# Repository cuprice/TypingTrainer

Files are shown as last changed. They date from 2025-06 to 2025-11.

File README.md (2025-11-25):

## タイピング練習用キーボード基板 Typing Haptic Trainer (Prototype)

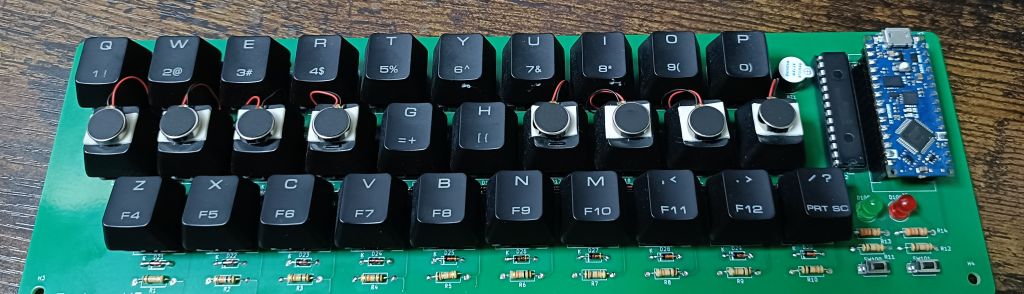
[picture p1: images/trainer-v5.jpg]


2025.11.25
Githubに公開してから数ヶ月経ちました。それ以来、触覚を利用したタッチタイピングの練習機械が他にもあることを知り、私のウェブ検索が十分でなかったと申し訳なく思いました。他の人々の作る機械はとても複雑でレベルの高いことも知り、私はまだまだ勉強不足であると思いました。もしお嫌でなければ、学習の活動を見守っていただければ幸いです。

I published my project on GitHub a few months ago.
After that, I learned that there are other typing training devices that use touch.
I felt sorry because my web search was not good enough.
I also found that other people’s devices are very complex and high-level, and I realized that I still have a lot to learn. If you don’t mind, I would be happy if you could watch my learning journey.

2025.11.23
基板を新しくしました！作った基板にArduino Nano Everyを組み込みました。
I made a new PCB and installed an Arduino Nano Every on it.

このリポジトリは回路・プログラミング初学者の学習用です。あたたかく見守っていただけると嬉しいです。

これは、プログラミングや回路の初心者である私が、自分なりに学びながら作ってみた実装基板です。  
8つのキーに振動する部品を付け、目で確認しなくてもどこを押せば良いかがわかる機能を目指しました。
公開しようと思ったきっかけは、似たようなアイデアのタイピング練習機を見つけることができなかったためです。

このリポジトリでは、タイピング練習を目的としたキーボード基板の設計データを公開しています。  
基板はKiCad 9.0で設計されています。振動するキー順番を変更するには、Arduinoのスケッチを編集する必要があります。

ただし、現在はアイデア段階であり、完全な完成品ではありません。今後の改善や追加機能に関しては更新を行う予定です。

This repository is for beginners who are learning circuits and programming.
I’d be happy if you could kindly support it.

This is a keyboard I made while learning programming and circuits by myself.
I am still a beginner, but I tried my best to build it.

I added small parts that can vibrate to 8 keys.
This way, you can feel which key to press without looking.

I decided to share this because I couldn't find a similar typing practice device online.

In this repository, I show the design data for this keyboard.
I made the design using KiCad 9.0.
If you want to change the order of the vibrating keys, you need to change the Arduino program.

Please note that this is still just an idea, not a finished product.
I want to improve it and add more features in the future.

---

## 特徴

- 10列、3段のキー(計30個)による練習用構成
- リセットスイッチ付き
- Cherry MX対応
- Arduino nano everyで完璧ではありませんが、一応動作確認済みです (後継機のモデルは動作未確認)
- KiCad 9.0で基板設計
- 基板サイズ：約261.1mm × 81.5mm
- 電源：Arduino nano every経由でのUSB給電

This is a practice keyboard layout with 30 keys, arranged in 10 columns and 3 rows.
It includes a reset switch. It's compatible with Cherry MX switches. I've confirmed it works with the Arduino nano every, although it's not perfect. I haven't tested it with newer Arduino models. The circuit board was designed using KiCad 9.0. The board size is about 261.1mm × 81.5mm, and it's powered by USB through the Arduino nano every.

どの段のキーを押せば良いかを、3段階のブザー音で教えるためのコードを加筆修正しました。上の段ならば3回鳴り、下の段ならば１回鳴り、真ん中の段なら２回鳴るという仕組みにしました。振動モーターがないキーの場合は、振動する長さを変えて位置を知らせるようにしました。

I changed the code to use three kinds of buzzer sounds to tell the user which row of keys to press.
If the key is on the top row, the buzzer beeps three times.
If the key is on the bottom row, it beeps one time.
If the key is on the middle row, it beeps two times.
For keys that do not have a vibration motor, the device changes the length of the vibration to show the position.

---

## ファイル構成

~~~

TypingTrainer/
    ├── TYPING-TRAINER-V5-2025-10-13_115341/ # KiCad設計ファイル
    ├── TYPING-TRAINER-V5.1.zip # ガーバーデータ（基板製造用）
    ├── TrainerV5active/ # Arduinoスケッチ
    ├── images/ # 写真・完成図
    ├── docs/ # 部品表
    └── README.md # このファイル

~~~

---

## 完成イメージ、回路図、動作の様子

基板写真

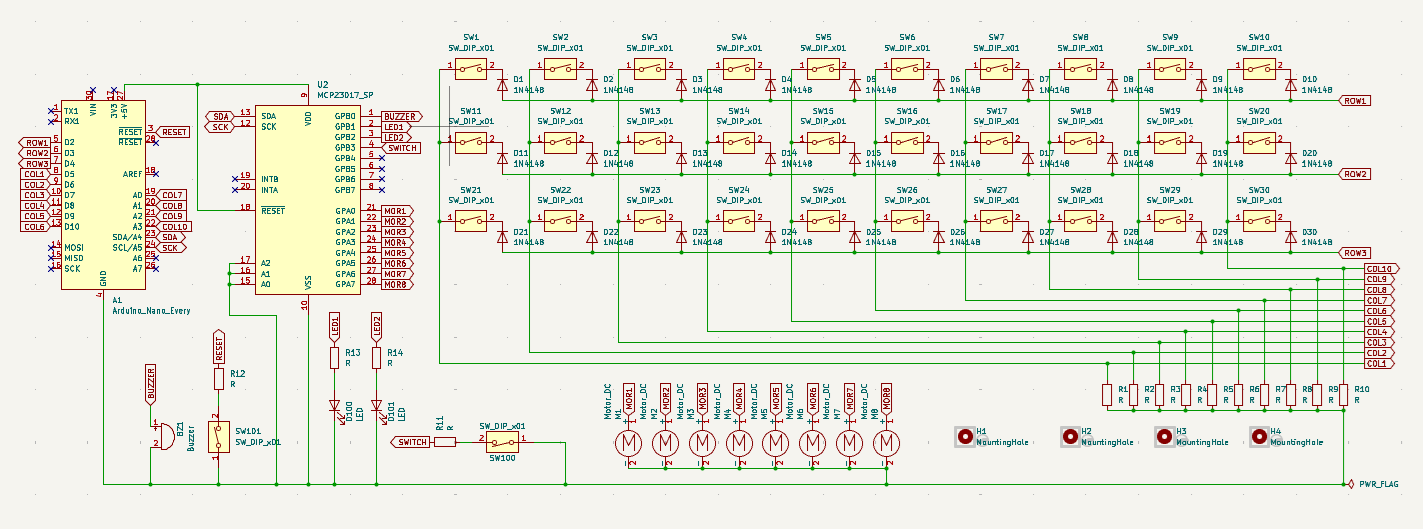
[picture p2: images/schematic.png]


[動作の様子](images/working.mp4)

[モーターの動き](images/shaker.mp4)

---

## 使い方
1. ガーバーファイルをPCBwayなどで製造依頼
2. 回路図などを見ながら部品を実装
3. Arduino nano everyをUSBケーブルでPCと接続
4. PCからArduinoへ、ファームウェアを書き込み

---

## 必要部品

| Value | Reference | Qty | 備考 | 画像 |
|---|---|-----|---|---|
| Arduino Nano Every  | A1 | 1 | マイクロコントローラー（ソケットピン経由で実装） |  |
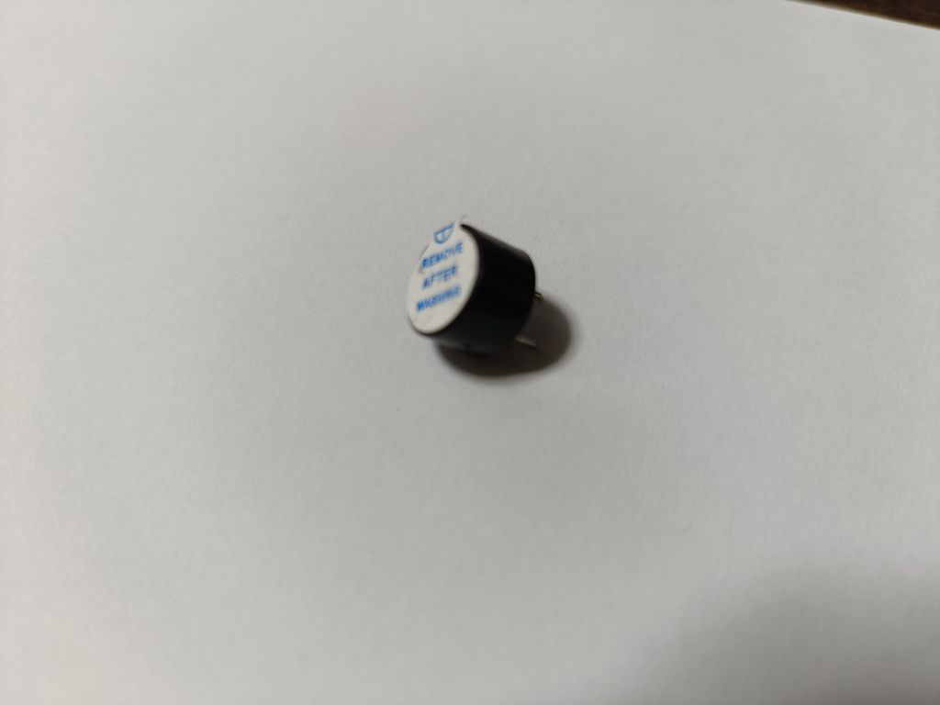
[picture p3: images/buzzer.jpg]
| Buzzer | BZ1 | 1 | ブザー |  |
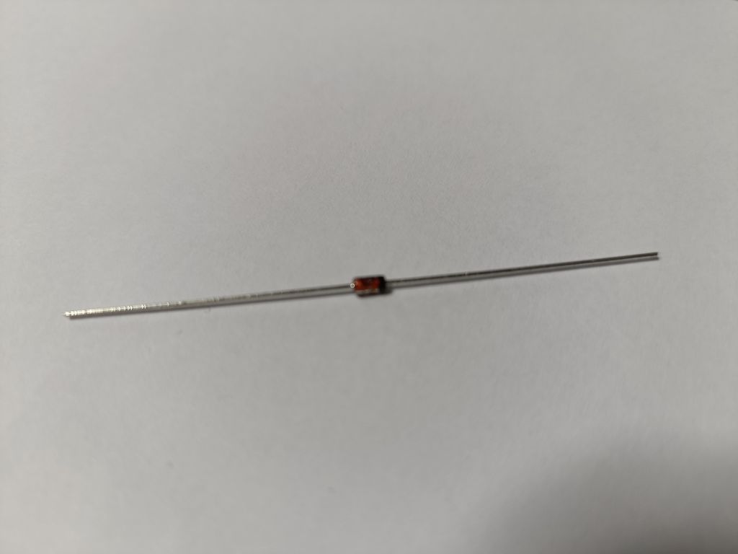
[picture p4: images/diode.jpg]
| 1N4148 | D1 〜 D30 | 30  | スイッチのマトリックス用ダイオード |  |
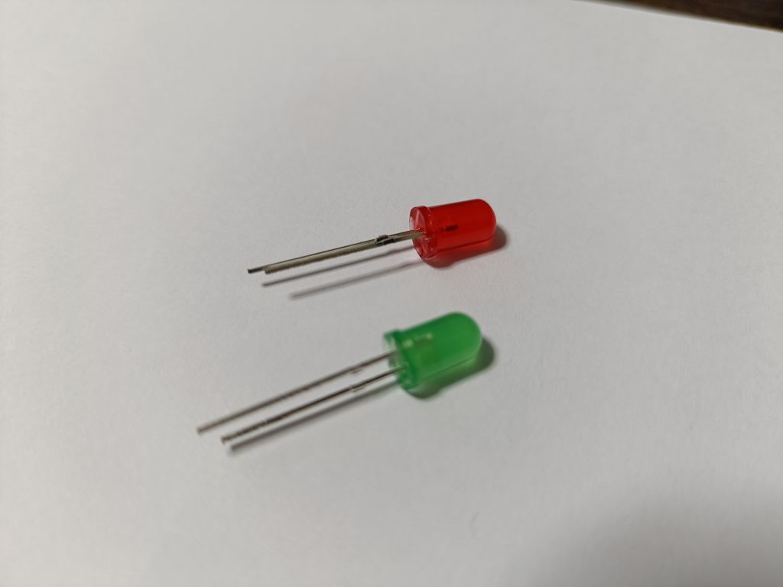
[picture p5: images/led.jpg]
| LED | D100, D101 | 2 | インジケーターLED |  |
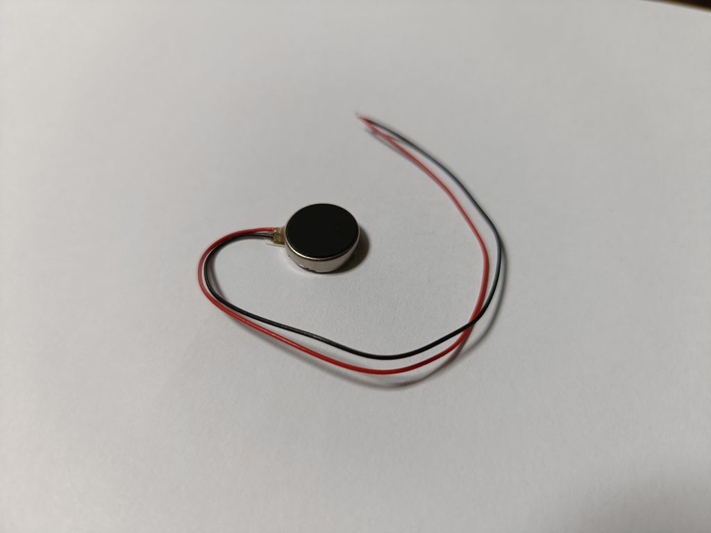
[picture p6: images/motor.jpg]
| Motor DC | M1 〜 M8 | 8 | DCモーター |  |
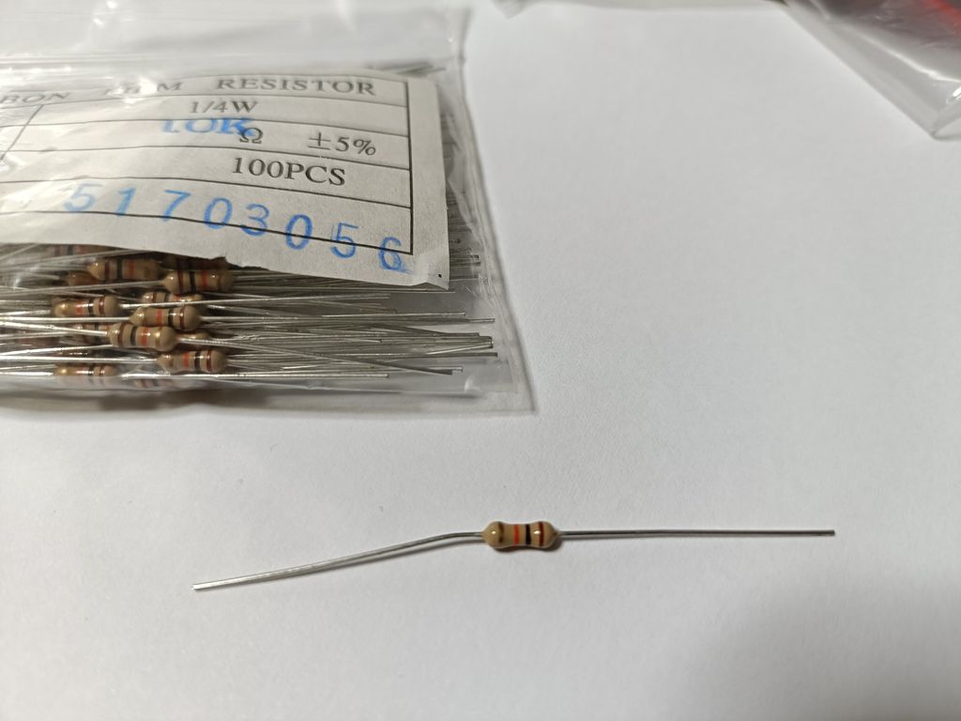
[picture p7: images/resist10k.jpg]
| 10k | R1 〜 R12 | 12  | 抵抗（10kΩ） |  |
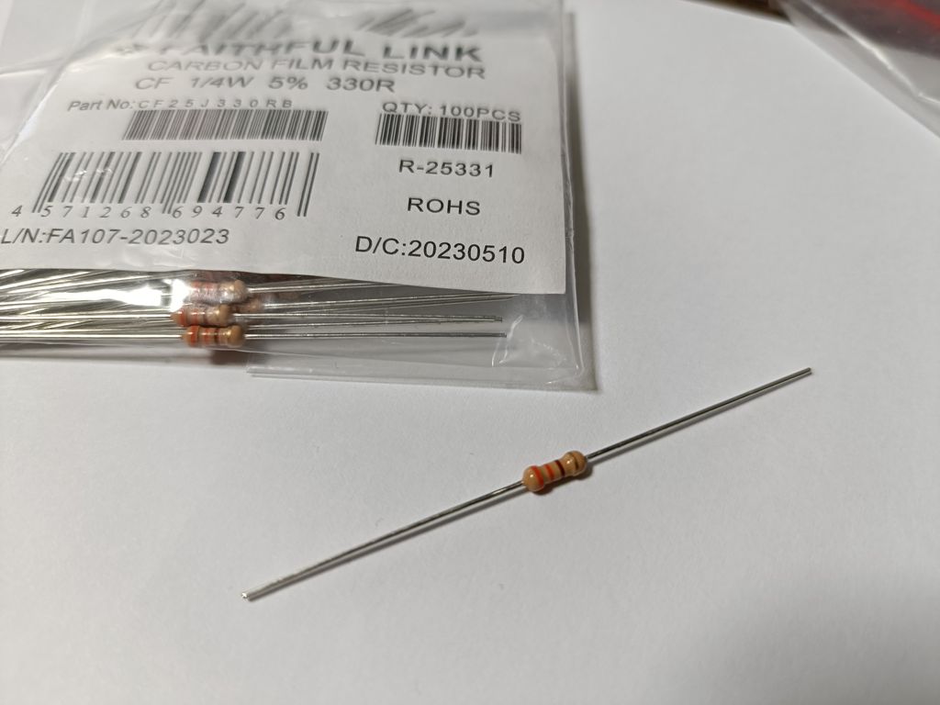
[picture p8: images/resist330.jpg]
| 330 | R13, R14 | 2 | 抵抗（330Ω, LED電流制限用） |  |
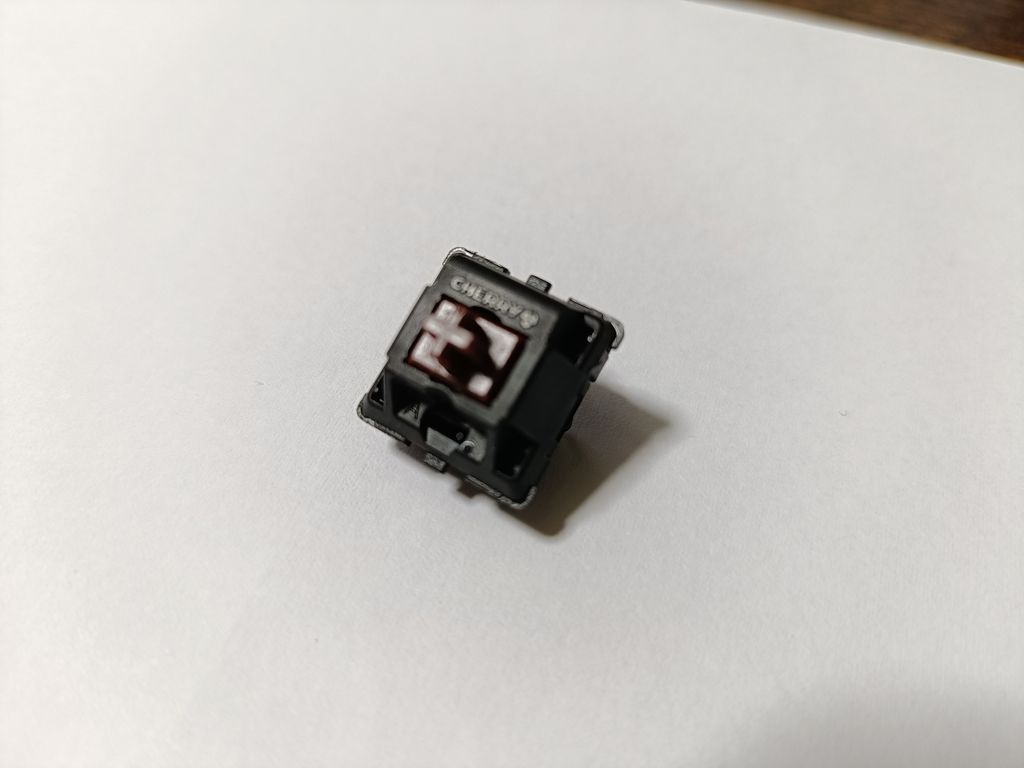
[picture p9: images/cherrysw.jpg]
| Cherry MX Switch | SW1 〜 SW30 | 30  | Cherry MX互換キースイッチ(キーキャップはお好みで) |  |
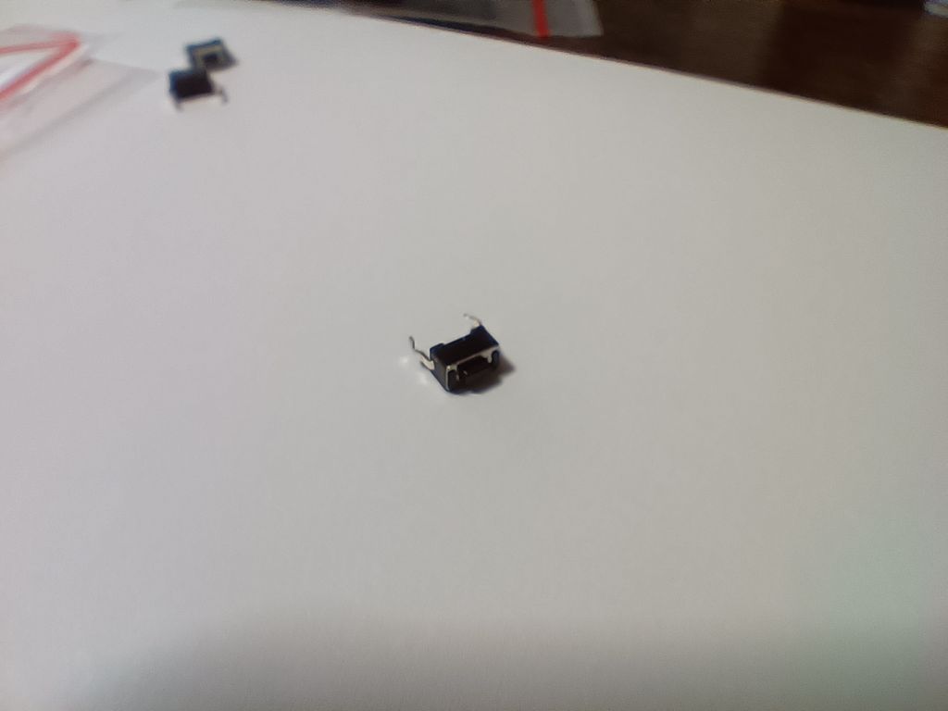
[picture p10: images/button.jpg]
| 2pin Button | SW100, SW101 | 2 | 2ピンのタクトスイッチなど |  |
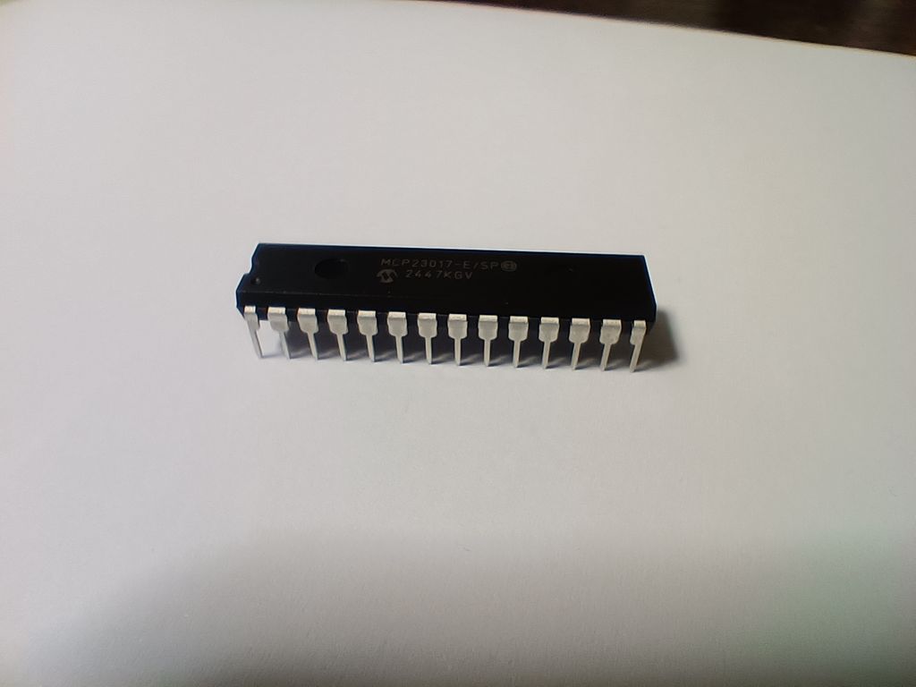
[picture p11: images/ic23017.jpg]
| MCP23017_SP | U2 | 1 | I/Oエキスパンダー（ICソケットの上に実装） |  |

---

## KiCad情報

- KiCad バージョン: 9.0
- 古いバージョンでは一部ファイルが開けない可能性があります。
- 最新バージョンでの動作は未確認です。

---

## ライセンス

この基板デザインは MIT ライセンスで公開しています。  

---

## よくある質問

準備中
**Q. ？**  
A. 

---

## 注意事項

- 初心者が学びながら作ったものなので、不完全な点もあるかもしれません。
- Arduinoスケッチの一部のコード作成に、生成AI（ChatGPT）を補助的に活用しました。

---

## Special Thanks

- ネット上のチュートリアルや電子工作記事の皆さま

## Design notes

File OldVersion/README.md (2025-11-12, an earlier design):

2025.11.12 今後の予定 Future Plan
基板にArduino Nano Everyを乗せる。AからZまでのキーを押せるようにする

I’m going to put an Arduino Nano Every on the board and make it work with keys from A to Z.

基板写真

2025.8.2 更新
どの段のキーを押せば良いかを、3段階のブザー音で教えるためのコードを加筆修正しました。上の段ならば高めの音、下の段ならば低めの音、真ん中の段ならその中間の音という仕組みにしました。

I changed the code to help users know which row of keys to press by using three different buzzer sounds.
A high sound means the top row, a low sound means the bottom row, and a middle sound means the middle row.

2025.7.27 追記
Arduinoのスケッチを、AIを使用して加筆修正し、複数の段にまたがって順番を指定できるように変更しました。また、段を切り替えるボタンは無効となっています。フォルダ名は、TrainerV4-i

I edited the Arduino sketch using AI. Now, you can set the order across several steps. The button to change steps is disabled. The folder name is TrainerV4-i.

## タイピング練習用キーボード基板
このリポジトリは回路・プログラミング初学者の学習用です。あたたかく見守っていただけると嬉しいです。

これは、プログラミングや回路の初心者である私が、自分なりに学びながら作ってみた実装基板です。  
8つのキーに振動する部品を付け、目で確認しなくてもどこを押せば良いかがわかる機能を目指しました。
公開しようと思ったきっかけは、似たようなアイデアのタイピング練習機を見つけることができなかったためです。

このリポジトリでは、タイピング練習を目的としたキーボード基板の設計データを公開しています。  
基板はKiCad 8.0で設計されています、基板上に部品を実装し、Arduino Uno R3に接続すれば使えるようになっています。
振動するキー順番を変更するには、Arduinoのスケッチを編集する必要があります。

ただし、現在はアイデア段階であり、完全な完成品ではありません。今後の改善や追加機能に関しては更新を行う予定です。

This repository is for beginners who are learning circuits and programming.
I’d be happy if you could kindly support it.

This is a keyboard I made while learning programming and circuits by myself.
I am still a beginner, but I tried my best to build it.

I added small parts that can vibrate to 8 keys.
This way, you can feel which key to press without looking.

I decided to share this because I couldn't find a similar typing practice device online.

In this repository, I show the design data for this keyboard.
I made the design using KiCad 8.0.
If you put the parts on the board and connect it to an Arduino Uno R3, it will work.
If you want to change the order of the vibrating keys, you need to change the Arduino program.

Please note that this is still just an idea, not a finished product.
I want to improve it and add more features in the future.

---

## 特徴

- 8列、3段のキー(計24個)による練習用構成
- リセットスイッチ、段の変更スイッチ機能付き
- Cherry MX対応
- Arduino Uno R3で完璧ではありませんが、一応動作確認済みです (後継機のモデルは動作未確認)
- KiCad 8.0で基板設計
- 基板サイズ：約215.9mm × 104.1mm
- 電源：Arduino Uno R3経由でのUSB給電

This is a practice keyboard layout with 24 keys, arranged in 8 columns and 3 rows.
It includes a reset switch and a switch to change the rows. It's compatible with Cherry MX switches. I've confirmed it works with the Arduino Uno R3, although it's not perfect. I haven't tested it with newer Arduino models. The circuit board was designed using KiCad 8.0. The board size is about 215.9mm x 104.1mm, and it's powered by USB through the Arduino Uno R3.

---

## ファイル構成

~~~

TypingTrainer/
    ├── TYPING-TRAINER-V4/ # KiCad設計ファイル
    ├── TYPING-TRAINER-V4.zip # ガーバーデータ（基板製造用）
    ├── TrainerV4_h-custom/ # Arduinoスケッチ
    ├── TrainerV4-i/ # Arduinoスケッチ (複数の段用スケッチ)
    ├── TrainerV4_i_example_words/ # Arduinoスケッチ (例文を使ったスケッチ)
    ├── images/ # 写真・完成図
    ├── docs/ # 部品表、ピン配置
    └── README.md # このファイル

~~~

---

## 完成イメージ

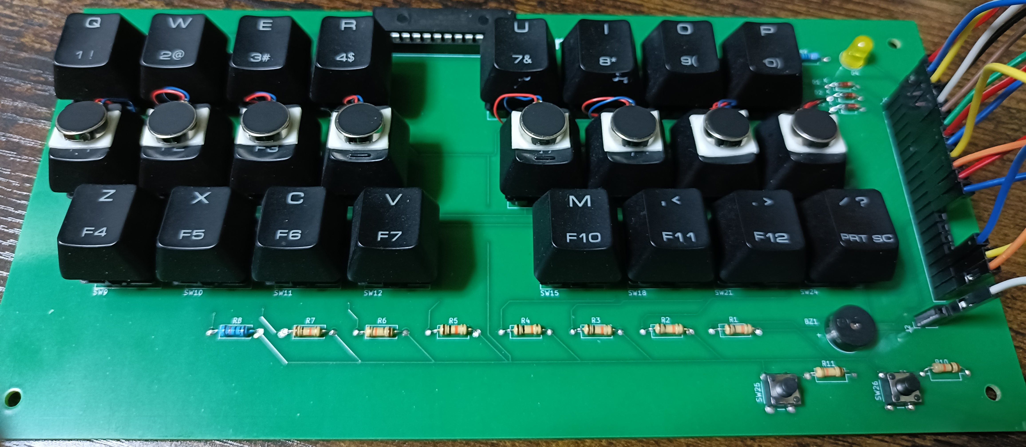
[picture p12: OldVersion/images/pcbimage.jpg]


---

## 使い方
1. ガーバーファイルをPCBwayなどで製造依頼
2. 回路図などを見ながら部品を実装
3. Arduino Uno R3と基板をジャンパワイヤで接続後、ArduinoをUSBケーブルでPCと接続
4. PCからArduinoへ、ファームウェアを書き込み

---

## 必要部品

| パーツ | 型番 / 種類 | 数量 | 備考 |
| :--- | :--- | :--- | :--- |
| マイコン | Arduino Uno R3 | 1個  | |
| USBケーブル | USB-A to USB-B | 1本  | PC接続用 |
| I/Oエキスパンダー | MCP23017 | 1個  | |
| ICソケット | 28ピン スリム300milタイプ | 1個  | IC直付けなら不要 |
| メカニカルスイッチ | Cherry MX互換  5ピン | 24個 | |
| キーキャップ | 上記スイッチ対応のもの | 24個 | |
| ダイオード | 1N4148 | 3個  | キーマトリクス用 |
| 抵抗 | 10kオーム | 10個 | |
| 抵抗 | 330オーム | 1個  | |
| LED (5mm) | 色はお好みで | 1個  | |
| タクトスイッチ | | 2個  | |
| パッシブ電子ブザー | | 1個  | \*1 |
| 振動モーター | | 8個  | |
| コネクタ用のピンソケット | 20pin | 1個  | |
| コネクタ用のピンソケット | 2pin | 1個  | |
| ジャンパ線 | 10cm～20cm | 20本くらいあれば | 

*1 ブザーのフットプリント参考URL https://jp.sameskydevices.com/product/resource/pcbfootprint/cmt-9648-85t

---

## KiCad情報

- KiCad バージョン: 8.0
- 古いバージョンでは一部ファイルが開けない可能性があります。
- 最新バージョンでの動作は未確認です。

---

## ライセンス

この基板デザインは MIT ライセンスで公開しています。  

---

## よくある質問

準備中
**Q. ？**  
A. 

---

## 注意事項

- 初心者が学びながら作ったものなので、不完全な点もあるかもしれません。
- Arduinoスケッチの一部のコード作成に、生成AI（ChatGPT）を補助的に活用しました。

---

## Special Thanks

- ネット上のチュートリアルや電子工作記事の皆さま

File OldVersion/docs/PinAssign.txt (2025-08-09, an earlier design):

20pin connector			
(TypingTrainer)          (Arduino)	
1pin  -----------------> 2pin	digital
2pin  -----------------> 3pin	digital
3pin  -----------------> 4pin	digital
4pin  -----------------> 5pin	digital
5pin  -----------------> 6pin	digital
6pin  -----------------> 7pin	digital
7pin  -----------------> 8pin	digital
8pin  -----------------> 9pin	digital
9pin  -----------------> 10pin	digital
10pin -----------------> 11pin	digital
11pin -----------------> 12pin	digital
12pin -----------------> A0	analog
13pin -----------------> 13pin	digital
14pin -----------------> n/a	
15pin -----------------> n/a	
16pin -----------------> A2	analog
17pin -----------------> A1	analog
18pin -----------------> A5	analog
19pin -----------------> A4	analog
20pin -----------------> 5V	
			
2pin connector --------> GND

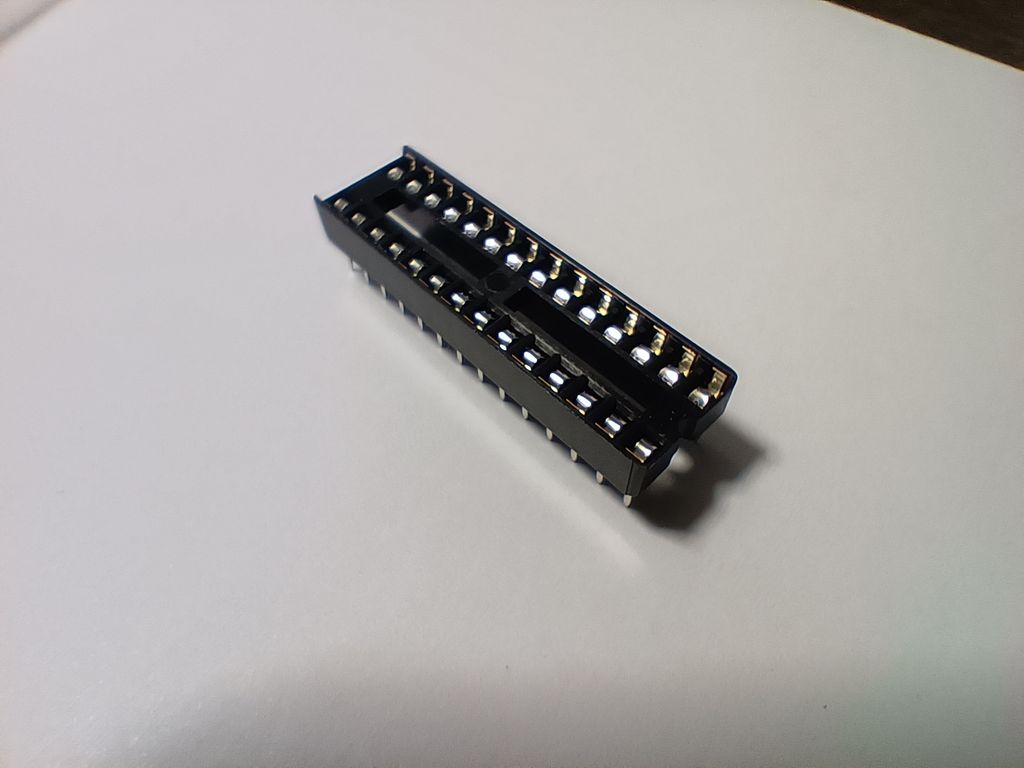
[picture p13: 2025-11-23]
images/icsocket.jpg

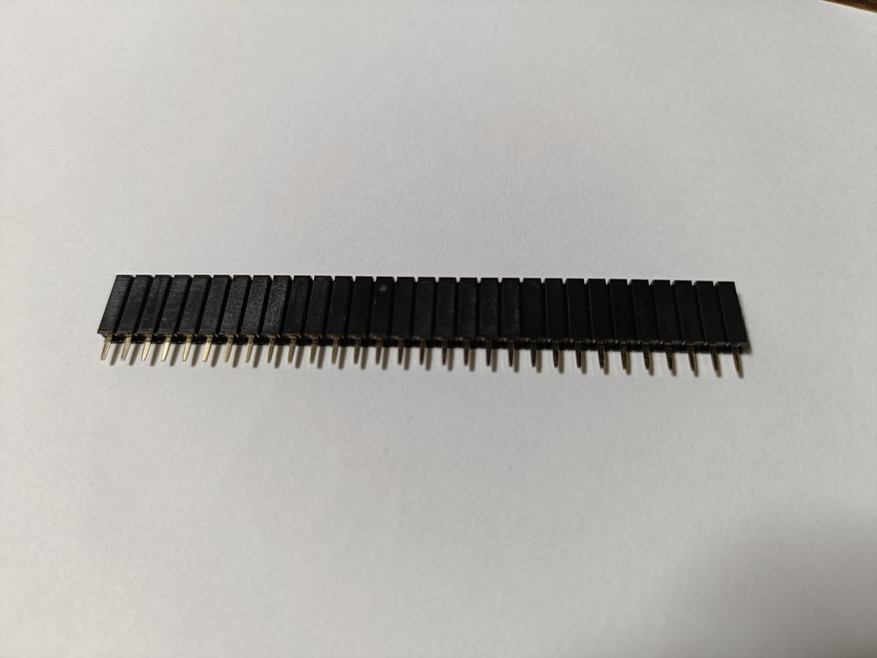
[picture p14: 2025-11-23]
images/socketpin.jpg

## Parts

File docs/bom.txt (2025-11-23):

Value	                Reference	Qty	備考
Arduino Nano Every	A1	        1	マイクロコントローラー
Buzzer	                BZ1	        1	ブザー
1N4148	                D1 〜 D30	30	スイッチのマトリックス用ダイオード
LED	                D100, D101	2	インジケーターLED
Motor DC              	M1 〜 M8	        8	DCモーター
10k	                R1 〜 R12	12	抵抗 (10kΩ)
330	                R13, R14	2	抵抗 (330Ω, LED電流制限用)
cherry mx switch	SW1 〜 SW30	30	Cherry MX互換キースイッチ
2pin button	        SW100, SW101	2	2ピンのタクトスイッチなど
MCP23017_SP	        U2	        1	I/Oエキスパンダー

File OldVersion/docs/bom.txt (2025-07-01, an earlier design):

# PartsList

| Value | Reference | Qty | DNP |
| :--- | :--- | :-- | :-- |
| Buzzer | BZ1 | 1 | |
| 1N4148 | D1,D2,D3 | 3 | |
| LED 5mm | D4 | 1 | |
| 20pin PInSocket | J1 | 1 | |
| 2pin PinSocket | J2 | 1 | |
| Motor_DC | M1,M2,M3,M4,M5,M6,M7,M8 | 8 | |
| 10k | R1,R2,R3,R4,R5,R6,R7,R8,R10,R11 | 10  | |
| 330 | R9 | 1 | |
| CherryMX Switch | SW1,SW2,SW3,SW4,SW5,SW6,SW7,SW8,SW9,SW10,SW11,SW12, | | |
| | SW13,SW14,SW15,SW16,SW17,SW18,SW19,SW20,SW21,SW22,SW23,SW24 | 24  | |
| Button Switch | SW25,SW26 | 2 | |
| MCP23017 | U2 | 1 | |

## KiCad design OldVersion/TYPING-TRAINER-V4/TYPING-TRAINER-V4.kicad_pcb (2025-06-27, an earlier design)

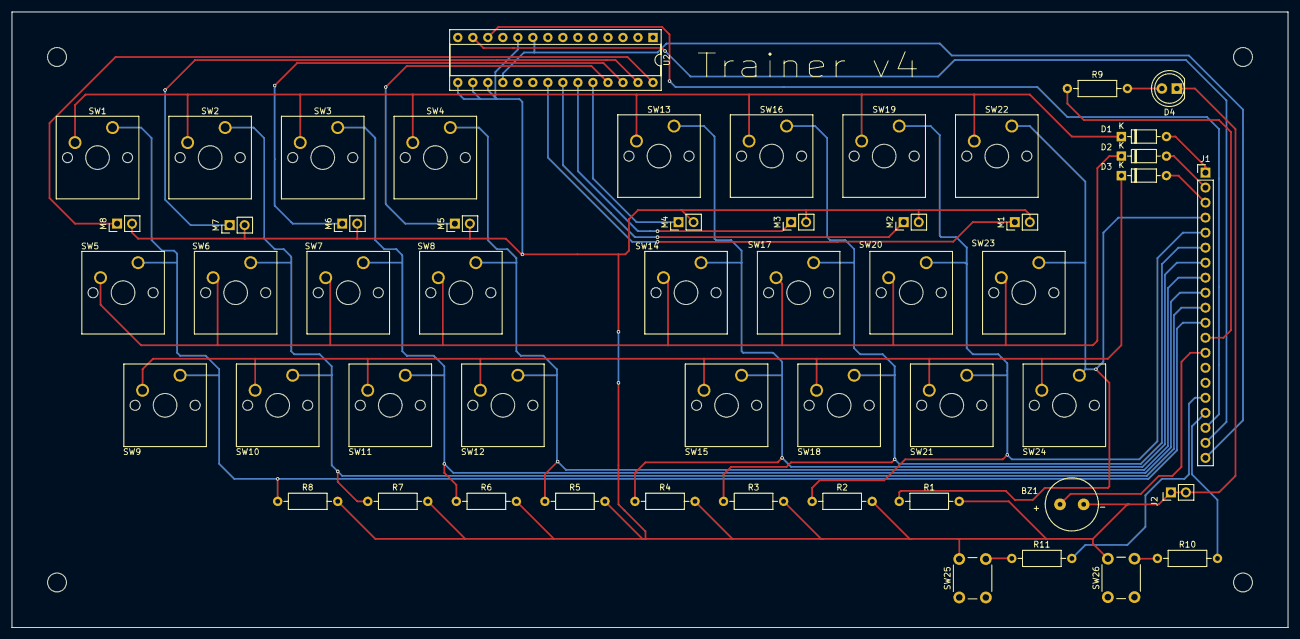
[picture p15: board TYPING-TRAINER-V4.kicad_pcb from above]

Board: 2 copper layers, 215.9 x 104.1 mm, 57 parts (0 on the bottom side), 33 nets.

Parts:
BZ1: Buzzer; XDCR_CMT-9648-85T
D1, D2, D3: 1N4148; D_DO-35_SOD27_P7.62mm_Horizontal
D4: LED; LED_D5.0mm_FlatTop
H1, H2, H3, H4: MountingHole; MountingHole_3.2mm_M3
J1: Conn_01x20_Pin; PinHeader_1x20_P2.54mm_Vertical
J2: Conn_01x02_Pin; PinHeader_1x02_P2.54mm_Vertical
M1, M2, M3, M4, M5, M6, M7, M8: Motor_DC; PinHeader_1x02_P2.54mm_Vertical
R1, R2, R3, R4, R5, R6, R7, R8, R9, R10, R11: R; R_Axial_DIN0207_L6.3mm_D2.5mm_P10.16mm_Horizontal
SW1, SW2, SW3, SW4, SW5, SW6, SW7, SW8, SW9, SW10, SW11, SW12, SW13, SW14, SW15, SW16, SW17, SW18, SW19, SW20, SW21, SW22, SW23, SW24: SW_DIP_x01; SW_Cherry_MX_1.00u_PCB
SW25, SW26: SW_DIP_x02b; SW_PUSH_6mm
U2: MCP23017_SP; CERDIP-28_W7.62mm_SideBrazed_Socket

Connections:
+5V: J1.20, U2.9 (VDD), U2.18 (~RESET)
GND: BZ1.2 (-), D4.1 (K), J2.1, J2.2, M1.2 (-), M2.2 (-), M3.2 (-), M4.2 (-), M5.2 (-), M6.2 (-), M7.2 (-), M8.2 (-), R1.2, R2.2, R3.2, R4.2, R5.2, R6.2, R7.2, R8.2, SW25.1, SW26.1, U2.10 (VSS), U2.15 (A0), U2.16 (A1), U2.17 (A2)
unnamed: BZ1.1 (+), J1.13
unnamed: D1.2 (A), J1.1
unnamed: D1.1 (K), SW1.2, SW2.2, SW3.2, SW4.2, SW13.2, SW16.2, SW19.2, SW22.2
unnamed: D2.2 (A), J1.2
unnamed: D2.1 (K), SW5.2, SW6.2, SW7.2, SW8.2, SW14.2, SW17.2, SW20.2, SW23.2
unnamed: D3.2 (A), J1.3
unnamed: D3.1 (K), SW9.2, SW10.2, SW11.2, SW12.2, SW15.2, SW18.2, SW21.2, SW24.2
unnamed: D4.2 (A), R9.2
unnamed: J1.4, R1.1, SW22.1, SW23.1, SW24.1
unnamed: J1.5, R2.1, SW19.1, SW20.1, SW21.1
unnamed: J1.6, R3.1, SW16.1, SW17.1, SW18.1
unnamed: J1.7, R4.1, SW13.1, SW14.1, SW15.1
unnamed: J1.8, R5.1, SW4.1, SW8.1, SW12.1
unnamed: J1.9, R6.1, SW3.1, SW7.1, SW11.1
unnamed: J1.10, R7.1, SW2.1, SW6.1, SW10.1
unnamed: J1.11, R8.1, SW1.1, SW5.1, SW9.1
unnamed: J1.12, R9.1
unnamed: J1.16, R11.2
unnamed: J1.17, R10.2
unnamed: J1.18, U2.12 (SCK)
unnamed: J1.19, U2.13 (SDA)
unnamed: M1.1 (+), U2.21 (GPA0)
unnamed: M2.1 (+), U2.22 (GPA1)
unnamed: M3.1 (+), U2.23 (GPA2)
unnamed: M4.1 (+), U2.24 (GPA3)
unnamed: M5.1 (+), U2.25 (GPA4)
unnamed: M6.1 (+), U2.26 (GPA5)
unnamed: M7.1 (+), U2.27 (GPA6)
unnamed: M8.1 (+), U2.28 (GPA7)
unnamed: R10.1, SW26.2
unnamed: R11.1, SW25.2

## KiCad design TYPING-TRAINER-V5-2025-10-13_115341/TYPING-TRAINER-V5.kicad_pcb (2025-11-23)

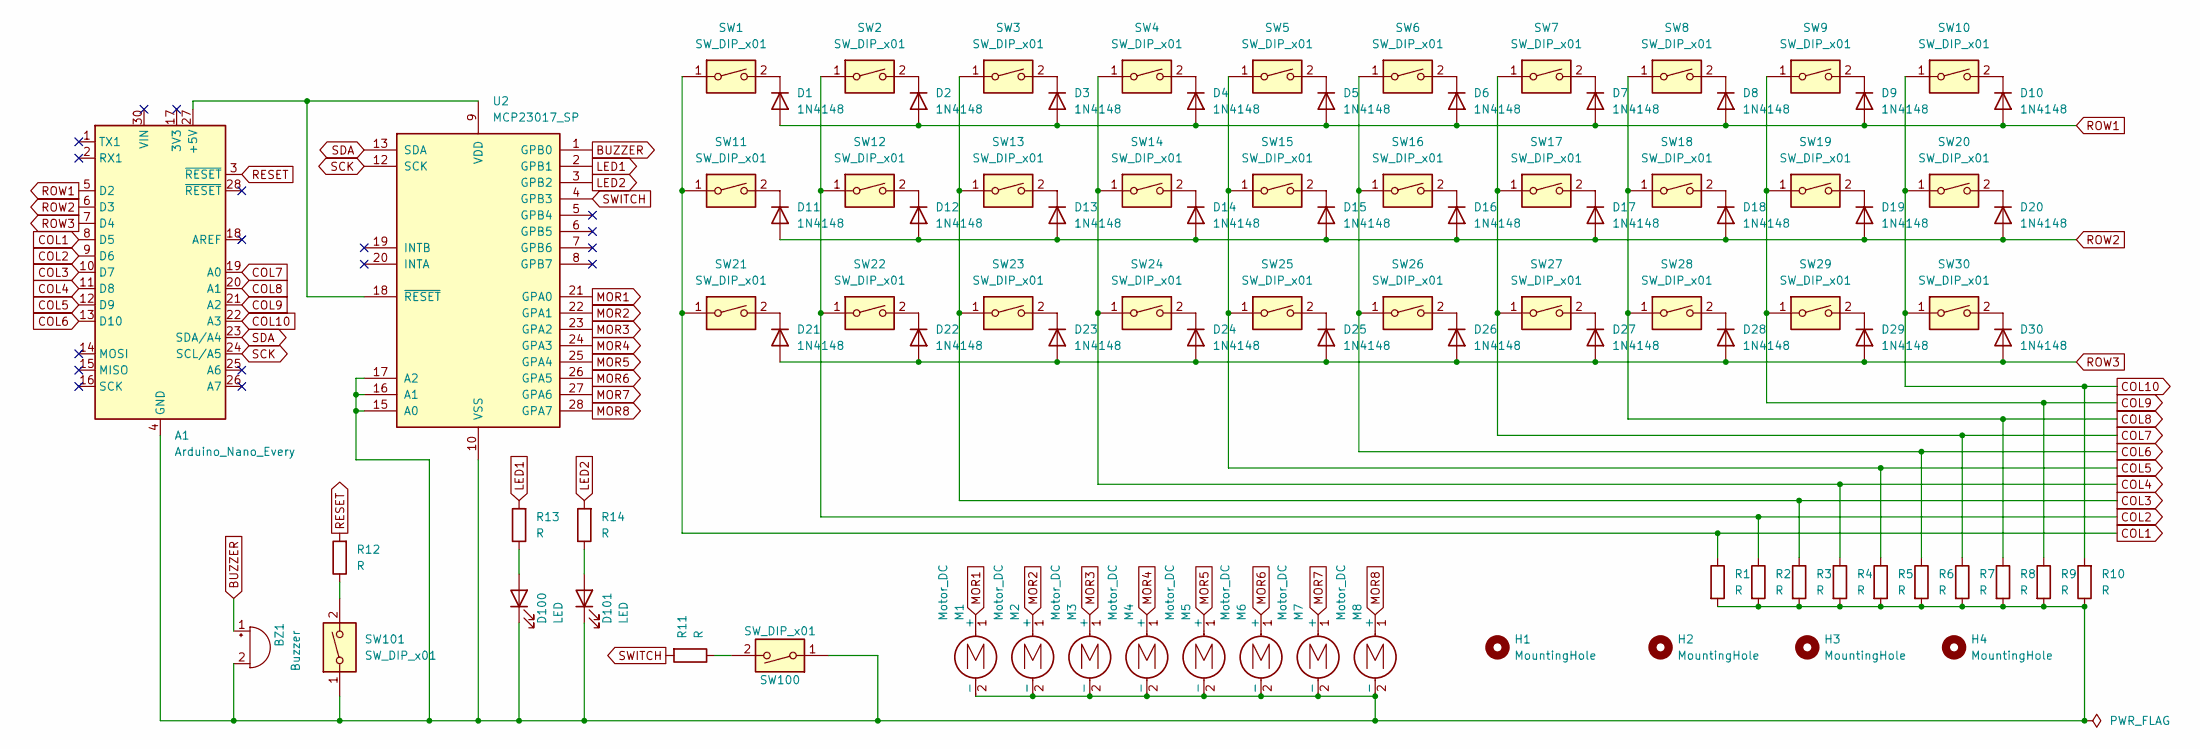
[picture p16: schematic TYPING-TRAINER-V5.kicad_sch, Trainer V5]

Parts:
A1: Arduino_Nano_Every; Arduino_Nano
BZ1: Buzzer; Buzzer_TDK_PS1240P02BT_D12.2mm_H6.5mm
D1, D2, D3, D4, D5, D6, D7, D8, D9, D10, D11, D12, D13, D14, D15, D16, D17, D18, D19, D20, D21, D22, D23, D24, D25, D26, D27, D28, D29, D30: 1N4148; D_DO-35_SOD27_P7.62mm_Horizontal-b
D100, D101: LED; LED_D5.0mm_FlatTop
H1, H2, H3, H4: MountingHole; MountingHole_3.2mm_M3
M1, M2, M3, M4, M5, M6, M7, M8: Motor_DC; PinHeader_1x02_P2.54mm_Vertical
R1, R2, R3, R4, R5, R6, R7, R8, R9, R10, R11, R12, R13, R14: R; R_Axial_DIN0207_L6.3mm_D2.5mm_P10.16mm_Horizontal
SW1, SW2, SW3, SW4, SW5, SW6, SW7, SW8, SW9, SW10, SW11, SW12, SW13, SW14, SW15, SW16, SW17, SW18, SW19, SW20, SW21, SW22, SW23, SW24, SW25, SW26, SW27, SW28, SW29, SW30: SW_DIP_x01; SW_Cherry_MX_1.00u_PCB
SW100, SW101: SW_DIP_x01; SW_PUSH_1P1T_6x3.5mm_H4.3_APEM_MJTP1243
U2: MCP23017_SP; DIP-28_W7.62mm

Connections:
BUZZER: BZ1.1 (+), U2.1 (GPB0)
COL1: A1.8 (D5), R1.1, SW1.1, SW11.1, SW21.1
COL2: A1.9 (D6), R2.1, SW2.1, SW12.1, SW22.1
COL3: A1.10 (D7), R3.1, SW3.1, SW13.1, SW23.1
COL4: A1.11 (D8), R4.1, SW4.1, SW14.1, SW24.1
COL5: A1.12 (D9), R5.1, SW5.1, SW15.1, SW25.1
COL6: A1.13 (D10), R6.1, SW6.1, SW16.1, SW26.1
COL7: A1.19 (A0), R7.1, SW7.1, SW17.1, SW27.1
COL8: A1.20 (A1), R8.1, SW8.1, SW18.1, SW28.1
COL9: A1.21 (A2), R9.1, SW9.1, SW19.1, SW29.1
COL10: A1.22 (A3), R10.2, SW10.1, SW20.1, SW30.1
LED1: R13.2, U2.2 (GPB1)
LED2: R14.2, U2.3 (GPB2)
MOR1: M1.1 (+), U2.21 (GPA0)
MOR2: M2.1 (+), U2.22 (GPA1)
MOR3: M3.1 (+), U2.23 (GPA2)
MOR4: M4.1 (+), U2.24 (GPA3)
MOR5: M5.1 (+), U2.25 (GPA4)
MOR6: M6.1 (+), U2.26 (GPA5)
MOR7: M7.1 (+), U2.27 (GPA6)
MOR8: M8.1 (+), U2.28 (GPA7)
unnamed: A1.27 (+5V), U2.9 (VDD), U2.18 (~RESET)
unnamed: A1.4 (GND), A1.29 (GND), BZ1.2 (-), D100.1 (K), D101.1 (K), M1.2 (-), M2.2 (-), M3.2 (-), M4.2 (-), M5.2 (-), M6.2 (-), M7.2 (-), M8.2 (-), R1.2, R2.2, R3.2, R4.2, R5.2, R6.2, R7.2, R8.2, R9.2, R10.1, SW100.1, SW101.1, U2.10 (VSS), U2.15 (A0), U2.16 (A1), U2.17 (A2)
unnamed: D1.1 (K), SW1.2
unnamed: D2.1 (K), SW2.2
unnamed: D3.1 (K), SW3.2
unnamed: D4.1 (K), SW4.2
unnamed: D5.1 (K), SW5.2
unnamed: D6.1 (K), SW6.2
unnamed: D7.1 (K), SW7.2
unnamed: D8.1 (K), SW8.2
unnamed: D9.1 (K), SW9.2
unnamed: D10.1 (K), SW10.2
unnamed: D11.1 (K), SW11.2
unnamed: D12.1 (K), SW12.2
unnamed: D13.1 (K), SW13.2
unnamed: D14.1 (K), SW14.2
unnamed: D15.1 (K), SW15.2
unnamed: D16.1 (K), SW16.2
unnamed: D17.1 (K), SW17.2
unnamed: D18.1 (K), SW18.2
unnamed: D19.1 (K), SW19.2
unnamed: D20.1 (K), SW20.2
unnamed: D21.1 (K), SW21.2
unnamed: D22.1 (K), SW22.2
unnamed: D23.1 (K), SW23.2
unnamed: D24.1 (K), SW24.2
unnamed: D25.1 (K), SW25.2
unnamed: D26.1 (K), SW26.2
unnamed: D27.1 (K), SW27.2
unnamed: D28.1 (K), SW28.2
unnamed: D29.1 (K), SW29.2
unnamed: D30.1 (K), SW30.2
unnamed: D100.2 (A), R13.1
unnamed: D101.2 (A), R14.1
unnamed: R11.1, SW100.2
unnamed: R12.1, SW101.2
RESET: A1.3 (~RESET), R12.2
ROW1: A1.5 (D2), D1.2 (A), D2.2 (A), D3.2 (A), D4.2 (A), D5.2 (A), D6.2 (A), D7.2 (A), D8.2 (A), D9.2 (A), D10.2 (A)
ROW2: A1.6 (D3), D11.2 (A), D12.2 (A), D13.2 (A), D14.2 (A), D15.2 (A), D16.2 (A), D17.2 (A), D18.2 (A), D19.2 (A), D20.2 (A)
ROW3: A1.7 (D4), D21.2 (A), D22.2 (A), D23.2 (A), D24.2 (A), D25.2 (A), D26.2 (A), D27.2 (A), D28.2 (A), D29.2 (A), D30.2 (A)
SCK: A1.24 (SCL/A5), U2.12 (SCK)
SDA: A1.23 (SDA/A4), U2.13 (SDA)
SWITCH: R11.2, U2.4 (GPB3)

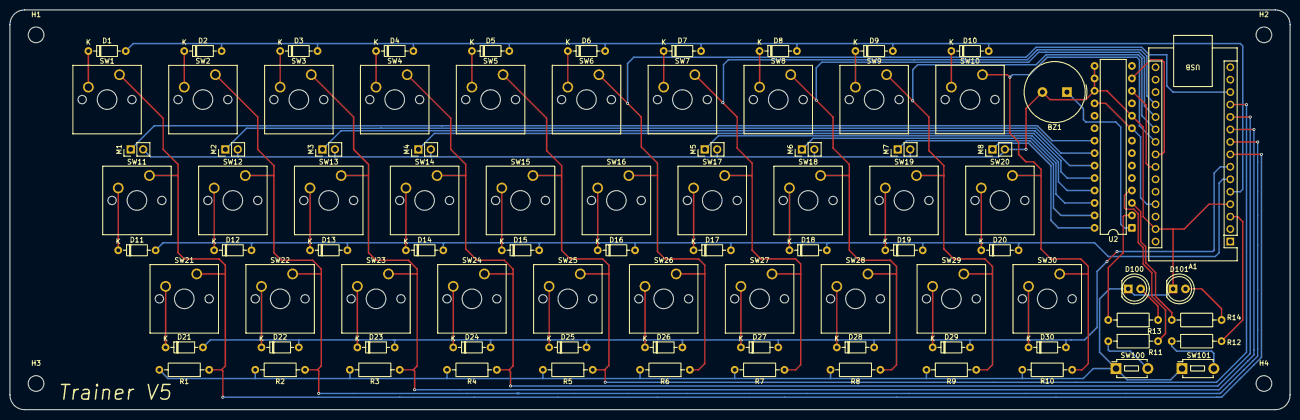
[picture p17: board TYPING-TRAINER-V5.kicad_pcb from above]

Board: 2 copper layers, 261.1 x 81.5 mm, 93 parts (0 on the bottom side), 64 nets.

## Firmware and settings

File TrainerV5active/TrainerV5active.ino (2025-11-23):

#include <Adafruit_MCP23X17.h>

Adafruit_MCP23X17 mcp;

const int ROWS = 3; // 行の数
const int COLS = 10; // 列の数

const int rowPins[ROWS] = {2, 3, 4}; // 行ピン (Arduinoピン)
const int colPins[COLS] = {5, 6, 7, 8, 9, 10, 14, 15, 16, 17}; // 列ピン (Arduinoピン)

// 0番から7番までのモーターピン
int motorPins[8] = {0, 1, 2, 3, 4, 5, 6, 7}; // MCPのピン0〜7

// 各段のモーター順序と、対応するキー入力の段・列を統合した配列
int motorOrder[] = {
    0, 1, 2, 3, 4, 5, 6, 7, 8, 9,
    0, 1, 2, 3, 4, 5, 6, 7, 8, 9,
    0, 1, 2, 3, 4, 5, 6, 7, 8, 9 // colPinsの配列（0から9）に対応
};

int keyRowOrder[] = {
    0, 0, 0, 0, 0, 0, 0, 0, 0, 0,
    1, 1, 1, 1, 1, 1, 1, 1, 1, 1,
    2, 2, 2, 2, 2, 2, 2, 2, 2, 2 // rowPinsの配列（0,1,2）に対応
};

const int TOTAL_SEQUENCE_LENGTH = sizeof(motorOrder) / sizeof(motorOrder[0]); // 全体のシーケンス長

int currentMotorPlace = 0; // 現在のモーターの場所
bool programEnd = false; // プログラム終了の状態

// LEDとブザーはMCP23017のピンに接続
const int led = 9; // MCP23017のピン9
const int buzzerPin = 8; // MCP23017のピン8

void setup() {
    Serial.begin(9600);
    mcp.begin_I2C(0x20);

    // MCPのLEDピン(9)とブザーピン(8)を出力に設定
    mcp.pinMode(buzzerPin, OUTPUT);
    mcp.pinMode(led, OUTPUT);
    mcp.digitalWrite(led, HIGH); // LEDを点灯
    
    // motorPinsに定義された全てのピンを出力に設定
    for (int i = 0; i < 8; i++) {
        mcp.pinMode(motorPins[i], OUTPUT);
    }

    // 行ピン（Arduinoピン）を入力プルアップに設定
    for (int i = 0; i < ROWS; i++) {
        pinMode(rowPins[i], INPUT_PULLUP);
    }

    // 列ピン（Arduinoピン）を出力に設定しHIGHに初期化
    for (int j = 0; j < COLS; j++) {
        pinMode(colPins[j], OUTPUT);
        digitalWrite(colPins[j], HIGH); // 初期状態はHIGH
    }
}

/**
 * アクティブブザーを短時間鳴らす関数。MCPのピンを使用。
 * @param duration 鳴らす時間（ミリ秒）
 */
void beep(int duration) {
    mcp.digitalWrite(buzzerPin, HIGH); // MCPのピンでブザーON
    delay(duration);
    mcp.digitalWrite(buzzerPin, LOW); // MCPのピンでブザーOFF
    delay(50); // 音と音の間隔
}

/**
 * 指定回数ブザーを鳴らす関数
 * @param count 鳴らす回数
 */
void multipleBeeps(int count) {
    for (int k = 0; k < count; k++) {
        beep(100); // 100ms鳴らす
    }
}

/**
 * 押されるべきキー（colPinsのインデックス）に基づいて、
 * 振動させるべきmotorPinsのピン番号（0〜7）を決定します。
 */
int getMotorPinIndex(int expectedCol) {
    // 1から4のとき (colPinsインデックス 0〜3)
    if (expectedCol >= 0 && expectedCol <= 3) {
        return expectedCol; // motorPins[0]〜motorPins[3]
    }
    // 7から10のとき (colPinsインデックス 6〜9)
    else if (expectedCol >= 6 && expectedCol <= 9) {
        // expectedCol 6, 7, 8, 9 を motorPinsのインデックス 4, 5, 6, 7 にマップ
        return expectedCol - 2; // motorPins[4]〜motorPins[7]
    }
    // colPinsが5 (インデックス 4) のとき
    else if (expectedCol == 4) {
        return 3; // motorPin 3 (motorPins[3]に対応)
    }
    // colPinsが6 (インデックス 5) のとき
    else if (expectedCol == 5) {
        return 4; // motorPin 4 (motorPins[4]に対応)
    }
    
    return -1; // 該当なし
}


void loop() {
    if (programEnd) return; // trueなら終了

    int expectedCol = motorOrder[currentMotorPlace]; // 現在期待される列（colPinsのインデックス）
    int expectedRow = keyRowOrder[currentMotorPlace];  // 現在期待される行（rowPinsのインデックス）

    int motorIndex = getMotorPinIndex(expectedCol); // 振動させるべき motorPins のインデックス

    // 【条件】colPinsのインデックスが4か5のときの特殊処理
    if (expectedCol == 4 || expectedCol == 5) {
        // 3. 特殊ブザーを5回鳴らす
        // multipleBeeps(5); 
        // delay(50);

        // 1. 段ごとのブザー通知 (何段目かを示す)
        switch (expectedRow) {
            case 0: multipleBeeps(3); break; // 上段 → 3回
            case 1: multipleBeeps(2); break; // 中段 → 2回
            case 2: multipleBeeps(1); break; // 下段 → 1回
        }
        
        // 2. モーターを振動 (colPins 4 -> motorPins[3], colPins 5 -> motorPins[4])
        if (motorIndex != -1) {
            mcp.digitalWrite(motorPins[motorIndex], HIGH);
            delay(300);
            mcp.digitalWrite(motorPins[motorIndex], LOW);
            delay(300);
            mcp.digitalWrite(motorPins[motorIndex], HIGH);
            delay(300);
        }
        
    } 
    // その他のモーターが割り当てられた列 (インデックス 0-3, 6-9)
    else if (motorIndex != -1) {
        // 段ごとのブザー通知 (音階の代わりに回数で通知)
        switch (expectedRow) {
            case 0: multipleBeeps(3); break; // 上段 → 3回
            case 1: multipleBeeps(2); break; // 中段 → 2回
            case 2: multipleBeeps(1); break; // 下段 → 1回
        }

        // モーターを振動
        mcp.digitalWrite(motorPins[motorIndex], HIGH);
        delay(200);
        mcp.digitalWrite(motorPins[motorIndex], LOW);
        delay(200);
    } 
    // モーターが割り当てられていない列 (この構成では発生しないはず)
    else {
        // 音階の代わりに回数で通知
        switch (expectedRow) {
            case 0: multipleBeeps(3); break;
            case 1: multipleBeeps(2); break;
            case 2: multipleBeeps(1); break;
        }
    }

    // キーマトリックスのスキャン処理
    for (int j = 0; j < COLS; j++) {
        digitalWrite(colPins[j], LOW); // 現在の列をLOWにする

        for (int i = 0; i < ROWS; i++) {
            if (digitalRead(rowPins[i]) == LOW) { // 行ピンがLOWになったらボタンが押されたと判断
                
                if (i == expectedRow && j == expectedCol) {
                    currentMotorPlace++; // 次のモーターに進む
                    
                    // 正解時のブザー: 短く2回
                    beep(200);
                    beep(200);

                    if (currentMotorPlace >= TOTAL_SEQUENCE_LENGTH) {
                        programEnd = true;
                        // 終了音: 少し長めのブザーを3回
                        beep(200);
                        beep(500);
                        beep(200);
                        beep(500);
                        beep(200);
                        beep(500);
                        beep(200);
                        beep(500);
                        mcp.digitalWrite(led, LOW); // 終了時にLEDを消灯
                    }

                    digitalWrite(colPins[j], HIGH); // 列を元に戻す
                    return; // 処理を終了し、次のループへ
                }
            }
        }
        digitalWrite(colPins[j], HIGH); // 列を元に戻す
    }
}

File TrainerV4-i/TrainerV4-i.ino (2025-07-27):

#include <Adafruit_MCP23X17.h>

Adafruit_MCP23X17 mcp;

const int ROWS = 3; // 行の数
const int COLS = 8; // 列の数

const int rowPins[ROWS] = {2, 3, 4}; // 行ピン
const int colPins[COLS] = {12, 11, 10, 9, 8, 7, 6, 5}; // 列ピン

// 0番から7番までのLEDピン
int motorPins[8] = {7, 6, 5, 4, 3, 2, 1, 0};

// 各段のLED点滅順序と、対応するキー入力の段・列を統合した配列
// motorOrderには「どのモーターを光らせるか（=どの列のキーが押されるべきか）」を、
// keyRowOrderには「どの段のキーが押されるべきか」を格納します。
// 例: { motorOrder[0], keyRowOrder[0] } の組み合わせで最初のキー入力を判定
int motorOrder[] = {0, 1, 2, 3, 4, 5, 6, 7,   // 段1のシーケンス
                    0, 1, 2, 3, 4, 5, 6, 7,   // 段2のシーケンス
                    0, 1, 2, 3, 4, 5, 6, 7};  // 段3のシーケンス

int keyRowOrder[] = {0, 0, 0, 0, 0, 0, 0, 0,   // 段1のキーはrow 0
                     1, 1, 1, 1, 1, 1, 1, 1,   // 段2のキーはrow 1
                     2, 2, 2, 2, 2, 2, 2, 2};  // 段3のキーはrow 2

const int TOTAL_SEQUENCE_LENGTH = sizeof(motorOrder) / sizeof(motorOrder[0]); // 全体のシーケンス長

int currentMotorPlace = 0; // 現在のLEDの場所（シーケンス全体での位置）
bool programEnd = false; // プログラム終了の状態

const int led = 14; // 基板のLED
const int buzzerPin = 13; // ブザー
const int noteC = 261;   // ド
const int noteD = 294;   // レ
const int noteE = 329;   // ミ
const int ResetPin = A1; // アナログピンA1をリセットスイッチ

void softwareReset() {
  asm volatile ("jmp 0"); // プログラム最初に
}

void setup() {
  Serial.begin(9600);
  pinMode(buzzerPin, OUTPUT);
  pinMode(led, OUTPUT);
  mcp.begin_I2C(0x20);

  pinMode(ResetPin, INPUT_PULLUP); 

  digitalWrite(led, HIGH);
  
  for (int i = 0; i <= 7; i++) {
    mcp.pinMode(i, OUTPUT);
  }

  for (int i = 0; i < ROWS; i++) {
    pinMode(rowPins[i], INPUT_PULLUP);
  }

  for (int j = 0; j < COLS; j++) {
    pinMode(colPins[j], OUTPUT);
    digitalWrite(colPins[j], HIGH); // 初期状態はHIGH
  }
}

void playTone(int note) {
  tone(buzzerPin, note);    // 指定した音階でブザーを鳴らす
  delay(200);             // 200ミリ秒待つ
  noTone(buzzerPin);      // 音を止める
}

void loop() {
  // リセットスイッチが押されたらソフトウェアリセット
  if (digitalRead(ResetPin) == LOW) {
    delay(50);
    if (digitalRead(ResetPin) == LOW) {
      softwareReset();
    }
  }

  if (programEnd) return; // trueなら終了

  int expectedMotor = motorOrder[currentMotorPlace]; // 現在期待される列（モーター）
  int expectedRow = keyRowOrder[currentMotorPlace];   // 現在期待される行

  // モーターを振動
  mcp.digitalWrite(motorPins[expectedMotor], HIGH);
  delay(200);
  mcp.digitalWrite(motorPins[expectedMotor], LOW);
  delay(200);

  // キーマトリックスのスキャン処理
  for (int j = 0; j < COLS; j++) {
    digitalWrite(colPins[j], LOW); // 現在の列をLOWにする

    for (int i = 0; i < ROWS; i++) {
      if (digitalRead(rowPins[i]) == LOW) { // 行ピンがLOWになったらボタンが押されたと判断
        // **押された行 (i) と期待される行 (expectedRow) が一致し、**
        // **押された列 (j) と期待される列 (expectedMotor) が一致する場合**
        if (i == expectedRow && j == expectedMotor) {
          currentMotorPlace++; // 次のモーターに進む（シーケンス全体で進む）

          // シーケンスの最後まで到達したか判定
          if (currentMotorPlace >= TOTAL_SEQUENCE_LENGTH) {
            programEnd = true; // プログラム終了
            playTone(noteC);
            playTone(noteD);
            playTone(noteE);
            playTone(noteD);
            playTone(noteC);
          }

          // キーが正しく押されたら、スキャンを中断して次のループへ
          digitalWrite(colPins[j], HIGH); // 現在の列をHIGHに戻すのを忘れない
          return; // loop()関数の最初に戻り、次のモーターを表示
        }
      }
    }
    digitalWrite(colPins[j], HIGH); // 現在の列をHIGHに戻す
  }
}

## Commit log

2025-07-01 3rd commit
    [TYPING-TRAINER-V4.kicad_sch]
2025-11-23 upgrade to v5
    [TYPING-TRAINER-V4.kicad_pcb, TYPING-TRAINER-V4.kicad_sch, TYPING-TRAINER-V5.kicad_pcb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]
